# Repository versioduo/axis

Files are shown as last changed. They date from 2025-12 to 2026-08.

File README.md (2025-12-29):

# V2 axis
🧭 MIDI Orientation Sensor and Accelerometer

Sends MIDI Control Change messages with Quaternion or Euler orientation data.

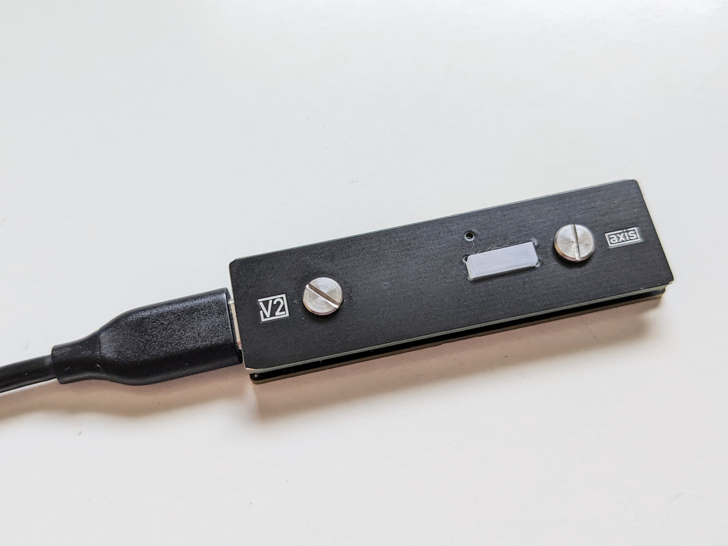
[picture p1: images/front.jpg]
axis hardware


## Setup
The device can be mounted at any orientation or angle, the reference frame / axes can be aligned to the current posion and stored in the device. This sequence identifies the Y axis (the axis of rotation between the button clicks) and the Z axis (the gravity at the second step):

- The device, or the body it is mounted on, points upwards / to the sky. A double-click of the the button, the LED turns green.

- The device points forward, the zero position. A single click, the LED turns orange. The axes of the sensor are now aligned and the rotation reset to zero.

- Any single click will set the rotation to zero, but not change the reference frame.

- A long-press double-click will store the calibration in the device, the LED flashes purple.

A long-press triple-click erases the stored data, the LED flashes purple.

## Control Change Mapping
Holding the device button down, suppresses all Control Change messages. The CC numbers can be configured in the Setting section. Pressing the blue button there, sends this single CC message; it can be used to map the CC in the Audio Workstation."

## Visualization
[versioduo.com/axis3d](https://versioduo.com/axis3d/)

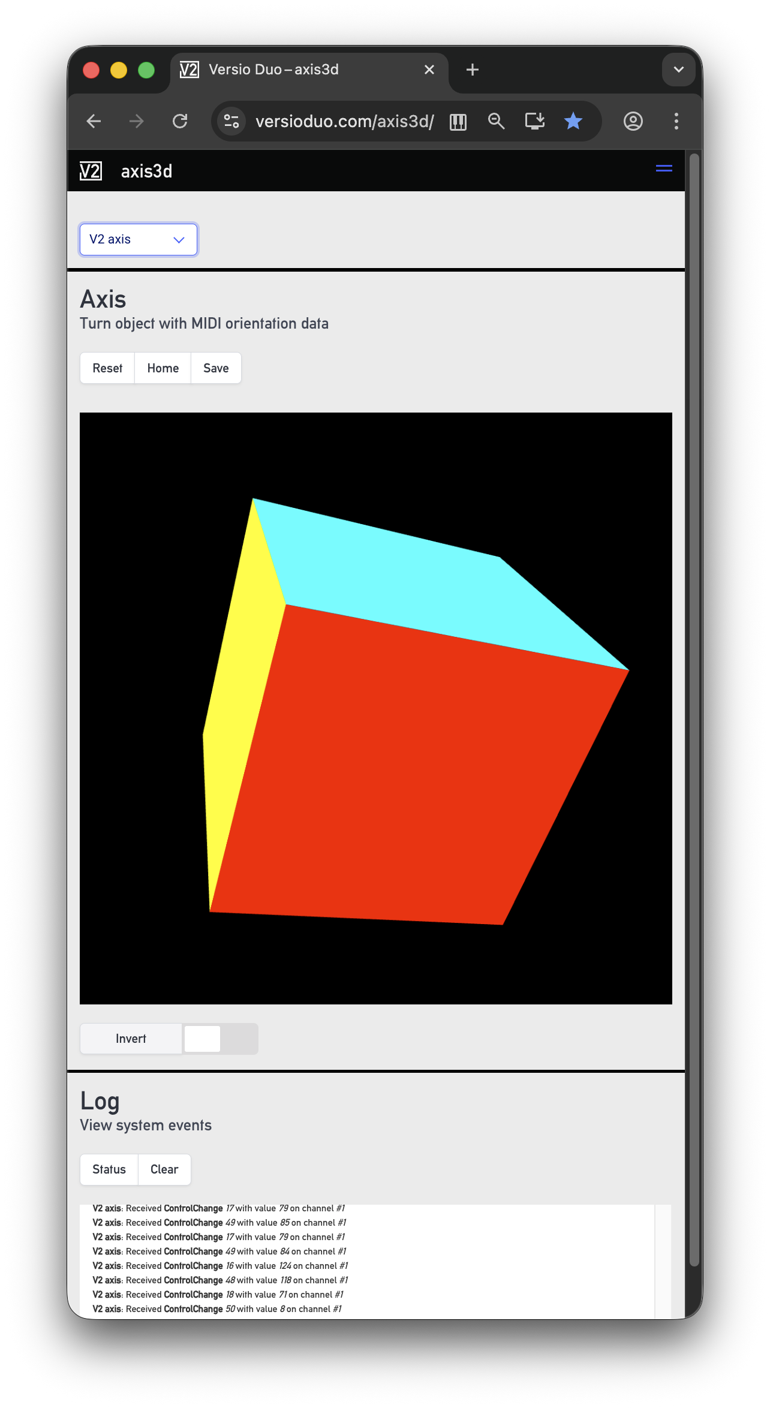
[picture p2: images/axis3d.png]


# Copying
Anyone can use this public domain work without having to seek authorisation, no one can ever own it.

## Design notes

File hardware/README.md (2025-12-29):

# V2 axis
🧭 MIDI Orientation Sensor and Accelerometer

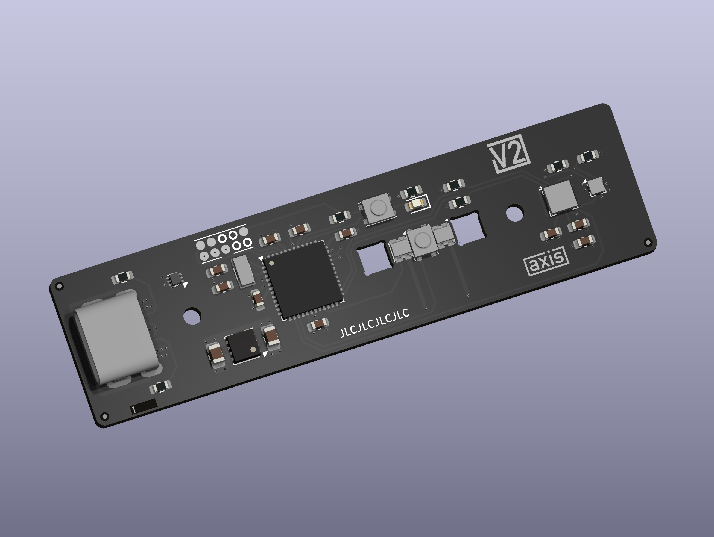
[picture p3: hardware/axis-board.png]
board


## Schematic
[PDF](axis.pdf)

## Bill Of Materials
[Interactive BOM](https://html-preview.github.io/?url=https://github.com/versioduo/axis/main/hardware/axis-bom.html)

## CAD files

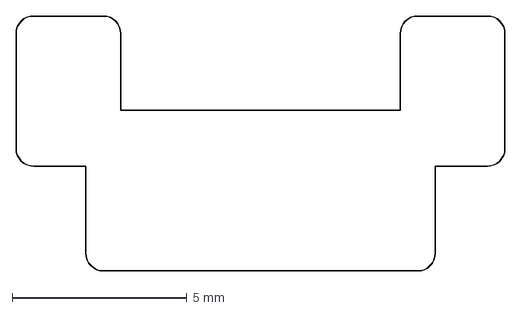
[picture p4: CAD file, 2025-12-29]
hardware/button-laser.dxf
14.0 x 7.30 mm

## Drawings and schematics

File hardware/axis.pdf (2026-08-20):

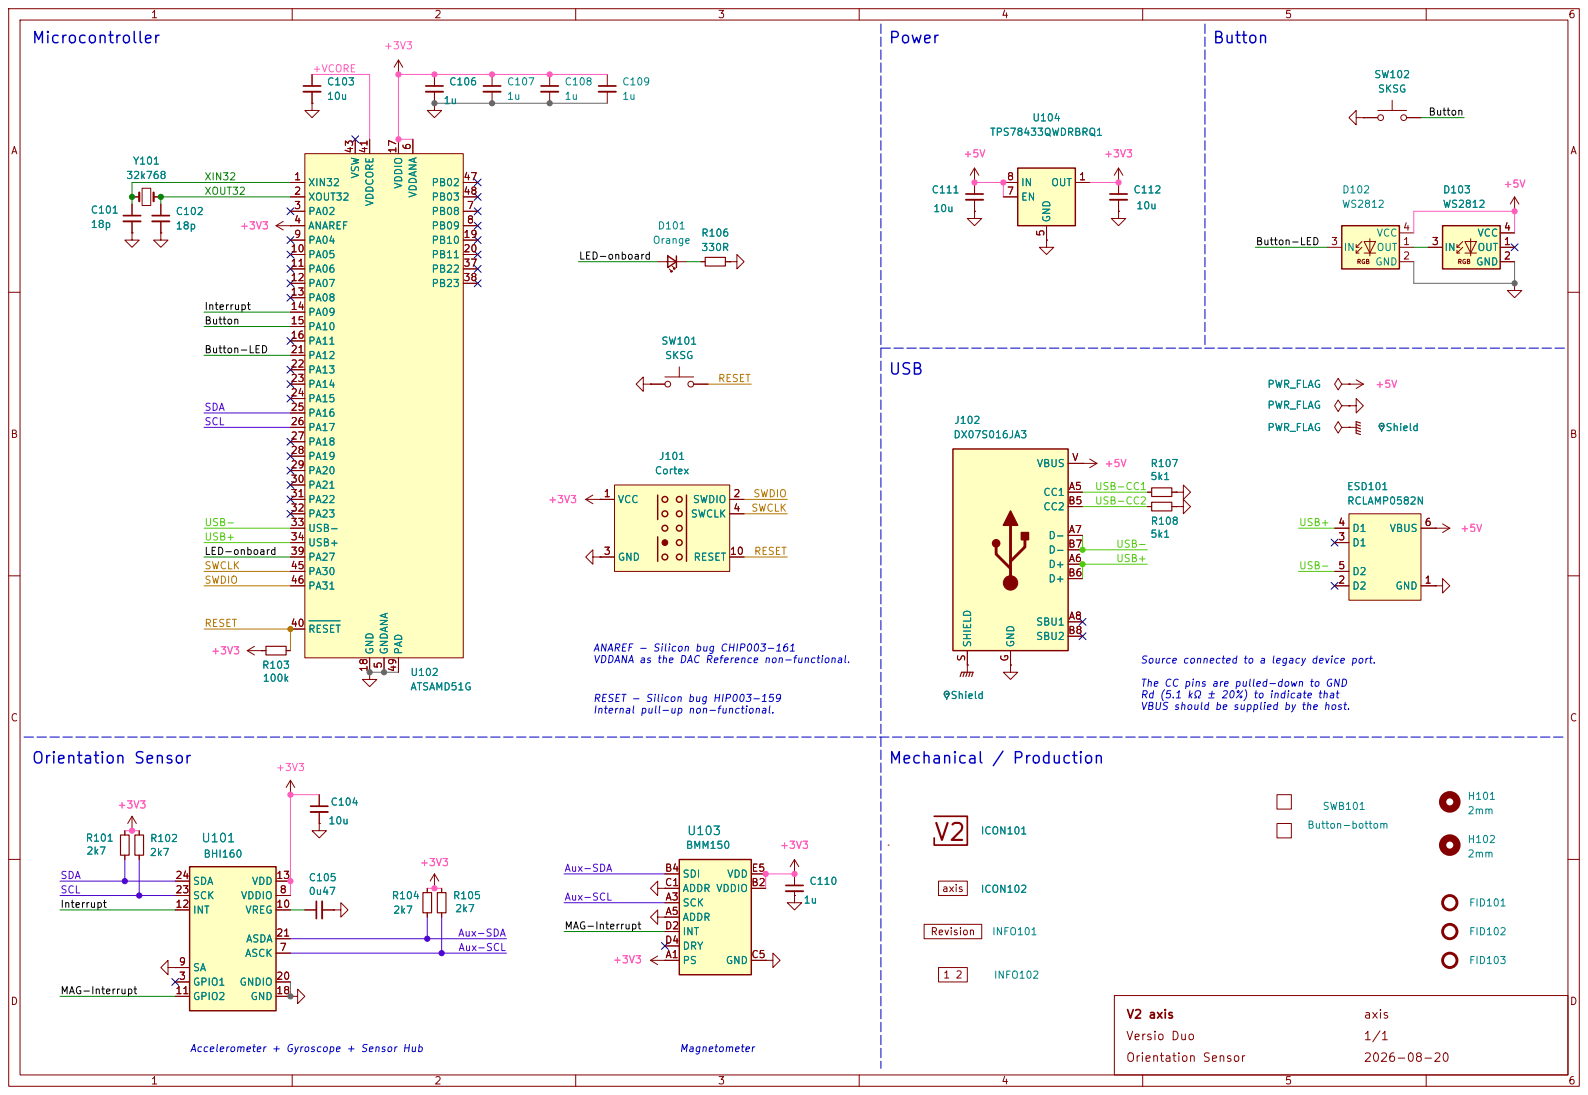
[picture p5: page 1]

Source connected to a legacy device port. The CC pins are pulled-down to GND

Rd (5.1 kΩ ± 20%) to indicate that VBUS should be supplied by the host. Magnetometer

Internal pull-up non-functional.

MAG-Interrupt SCL MAG-Interrupt

Accelerometer + Gyroscope + Sensor Hub

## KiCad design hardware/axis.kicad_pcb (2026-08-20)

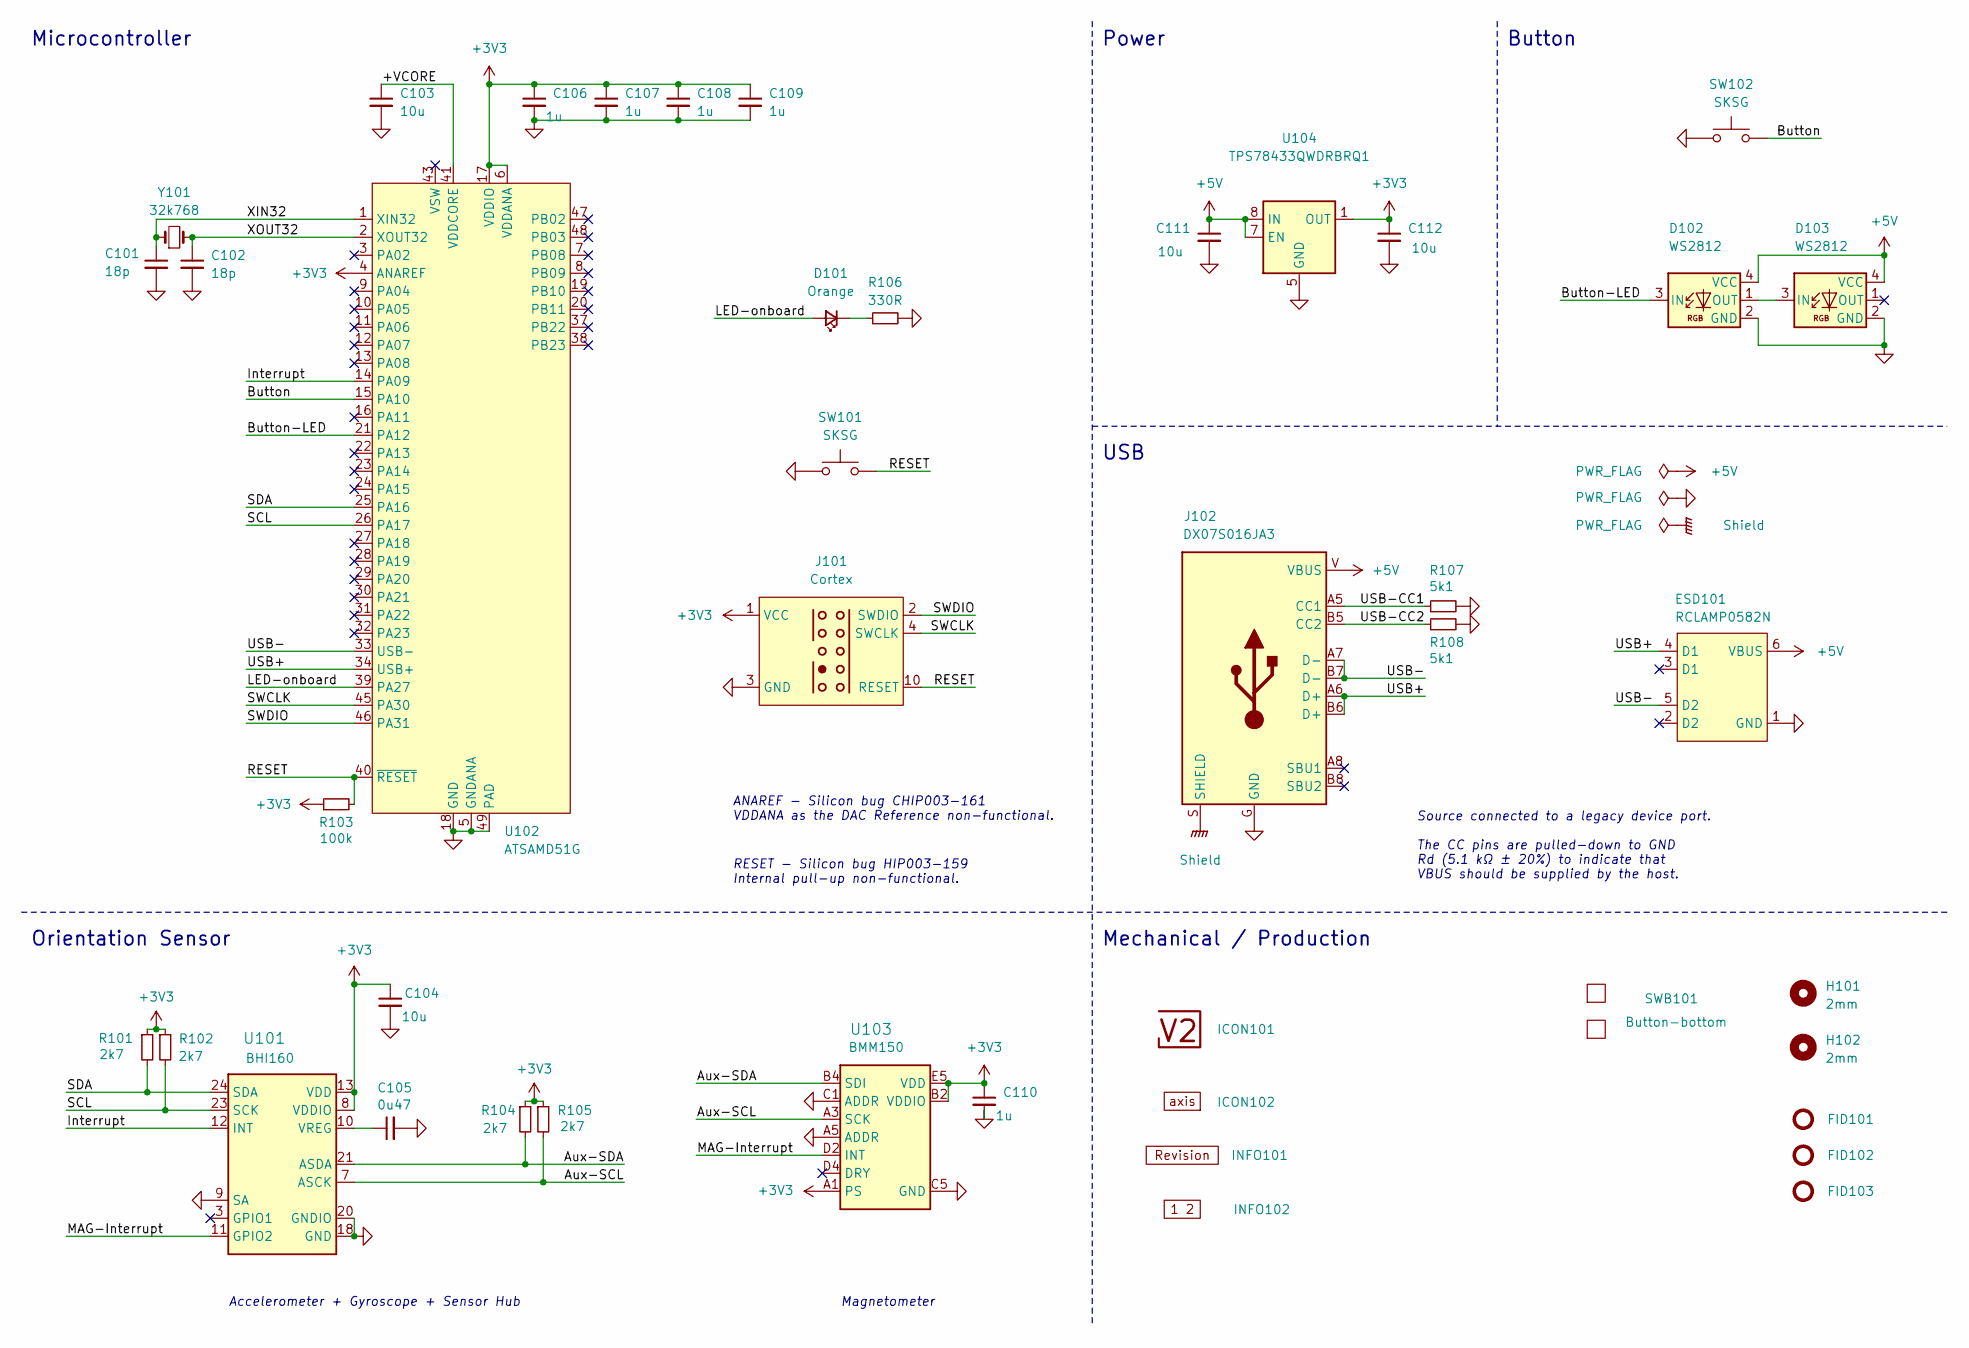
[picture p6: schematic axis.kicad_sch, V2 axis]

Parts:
C101, C102: 18p; C_1608; Rating 50V; Mouser 810-CGA3E2C0G1H180J
C103, C104: 10u; C_1608; Rating 10V; Mouser 810-C1608X6S1A106M
C105: 0u47; C_1608; Rating 50V; Mouser 810-CGA3E3X7R1H474KB
C106, C107, C108, C109, C110: 1u; C_1608; Rating 50V; Mouser 810-CGA3E3X7R1H105K0
C111, C112: 10u; C_2012; Rating 25V; Mouser 810-C2012X5R1E106K
D101: Orange; LED_1608; Rating 605nm; Mouser 755-SML-D12D1WT86
D102, D103: WS2812; WS2812-2020; Rating 15mA; LCSC C965555
ESD101: RCLAMP0582N; SLP1210N6; Rating 20kV; Mouser 947-RCLAMP0582N.TCT
FID101, FID102, FID103: Fiducial_Paste; Fiducial_0.5mm_Mask1mm_Paste
H101, H102: 2mm; MountingHole_2mm
ICON101: V2-logo; Logo_Small
ICON102: Board_axis; Board_axis_Small
INFO101: Revision
INFO102: Layer_Numbers-4
J101: Cortex
J102: DX07S016JA3; JAE_DX07S016JA3; Rating USB2.0; Mouser 656-DX07S016JA3R1500
R101, R102, R104, R105: 2k7; R_1608; Rating 100mW; Mouser 71-CRCW06032K70FKEAC
R103: 100k; R_1608; Rating 100mW; Mouser 71-CRCW0603100KFKEAC
R106: 330R; R_1608; Rating 100mW; Mouser 71-CRCW0603330RFKEAC
R107, R108: 5k1; R_1608; Rating 100mW; Mouser 71-CRCW06035K10FKEAC
SW101, SW102: SKSG; Rating 1.6N; Mouser 688-SKSGACE010
SWB101: Button-bottom; PCB_Button-bottom
U101: BHI160; LGA24-3x3; LCSC C464452
U102: ATSAMD51G; QFN-48-1EP_7x7mm_P0.5mm_EP5.45x5.45mm_ThermalVias; Rating Cortex-M4F; Mouser 556-ATSAMD51G19AMU
U103: BMM150; WLCSP-1.56x1.56; LCSC C171681
U104: TPS78433QWDRBRQ1; VSON-8-1_3x3mm_P0.65_EP1.65x2.4mm; Rating 300mA; Mouser 595-TPS78433QWDRBRQ1
Y101: 32k768; Crystal_SMD_3215-2Pin_3.2x1.5mm; Rating 10ppm; Mouser 815-ABS0716632.768KT

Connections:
+3V3: C104.1, C106.1, C107.1, C108.1, C109.1, C110.1, C112.1, J101.1 (VCC), R101.1, R102.1, R103.1, R104.1, R105.1, U101.8 (VDDIO), U101.13 (VDD), U102.4 (ANAREF), U102.6 (VDDANA), U102.17 (VDDIO), U102.36 (VDDIO), U102.44 (VDDIO), U103.A1 (PS), U103.B2 (VDDIO), U103.E5 (VDD), U104.1 (OUT)
+5V: C111.1, D102.4 (VCC), D103.4 (VCC), ESD101.6 (VBUS), J102.V (VBUS), U104.7 (EN), U104.8 (IN)
/+VCORE: C103.1, U102.41 (VDDCORE)
/Aux-SCL: R105.2, U101.7 (ASCK), U103.A3 (SCK)
/Aux-SDA: R104.2, U101.21 (ASDA), U103.B4 (SDI)
/Button: SW102.2, U102.15 (PA10)
/Button-LED: D102.3 (IN), U102.21 (PA12)
/Interrupt: U101.12 (INT), U102.14 (PA09)
/LED-onboard: D101.2 (A), U102.39 (PA27)
/MAG-Interrupt: U101.11 (GPIO2), U103.D2 (INT)
/RESET: J101.10 (RESET), R103.2, SW101.2, U102.40 (~RESET)
/SCL: R102.2, U101.23 (SCK), U102.26 (PA17)
/SDA: R101.2, U101.24 (SDA), U102.25 (PA16)
/SWCLK: J101.4 (SWCLK), U102.45 (PA30)
/SWDIO: J101.2 (SWDIO), U102.46 (PA31)
/Shield: J102.S (SHIELD)
/USB+: ESD101.4 (D1), J102.A6 (D+), J102.B6 (D+), U102.34 (USB+)
/USB-: ESD101.5 (D2), J102.A7 (D-), J102.B7 (D-), U102.33 (USB-)
/USB-CC1: J102.A5 (CC1), R107.1
/USB-CC2: J102.B5 (CC2), R108.1
/XIN32: C101.1, U102.1 (XIN32), Y101.1
/XOUT32: C102.1, U102.2 (XOUT32), Y101.2
GND: C101.2, C102.2, C103.2, C104.2, C105.2, C106.2, C107.2, C108.2, C109.2, C110.2, C111.2, C112.2, D102.2 (GND), D103.2 (GND), ESD101.1 (GND), J101.3 (GND), J101.5 (GND), J102.G (GND), R106.2, R107.2, R108.2, SW101.1, SW102.1, U101.9 (SA), U101.18 (GND), U101.20 (GNDIO), U102.5 (GNDANA), U102.18 (GND), U102.35 (GND), U102.42 (GND), U102.49 (PAD), U103.A5 (ADDR), U103.C1 (ADDR), U103.C5 (GND), U103.E1 (GND), U103.E3 (GND), U104.5 (GND), U104.9 (GND)
unnamed: D101.1 (K), R106.1
unnamed: D102.1 (OUT), D103.3 (IN)
unnamed: C105.1, U101.10 (VREG)

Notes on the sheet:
 ANAREF - Silicon bug CHIP003-161 VDDANA as the DAC Reference non-functional.
RESET -  Silicon bug HIP003-159 Internal pull-up non-functional.
 Source connected to a legacy device port. The CC pins are pulled-down to GND Rd (5.1 kΩ ± 20%) to indicate that VBUS should be supplied by the host.
Button
Mechanical / Production
Magnetometer
Power
Accelerometer + Gyroscope + Sensor Hub
Microcontroller
USB
Orientation Sensor

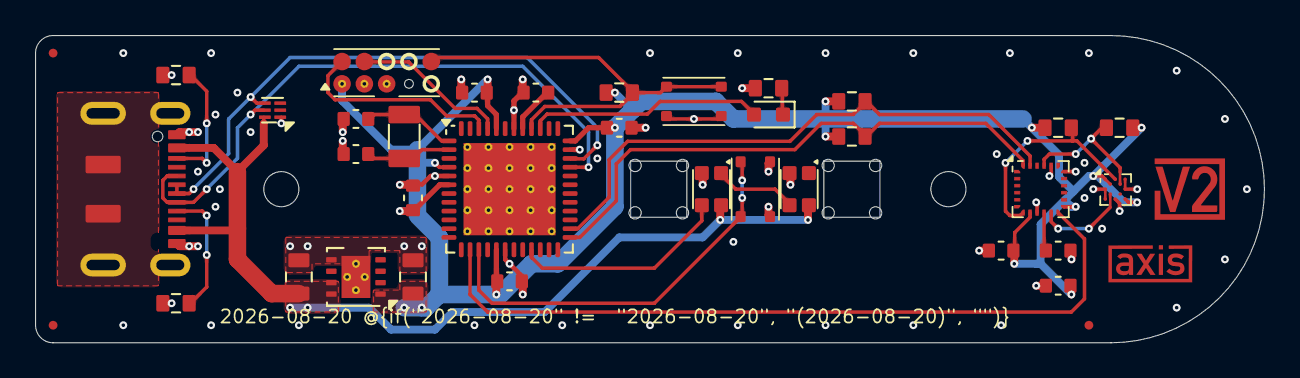
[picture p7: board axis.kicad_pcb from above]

Board: 4 copper layers, 70.0 x 17.5 mm, 43 parts (0 on the bottom side), 25 nets.

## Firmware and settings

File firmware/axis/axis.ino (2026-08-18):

#include <V2BHY1.h>
#include <V2Buttons.h>
#include <V2Device.h>
#include <V2LED.h>
#include <V2Link.h>
#include <V2MIDI.h>
#include <Wire.h>

namespace {
  V2Device::Info   Info{V2DeviceInfo("com.versioduo.axis", 8, "versioduo:samd:axis")};
  V2LED::WS2812<2> LED(PIN_LED_WS2812, sercom2, SPI_PAD_0_SCK_1, PIO_SERCOM);

  class Sensor : public V2BHY1 {
  public:
    Sensor() : V2BHY1(&Wire, PIN_SENSOR_INTERRUPT) {}

    // Subtract the recorded home postion to return the relative orientation to it.
    auto getRotation() -> V23D::Quaternion {
      return _setup.home * readCalibrated();
    }

    auto getAcceleration() -> V23D::Vector3 {
      return getGyroscope();
    }

    void updateLED() {
      switch (_setup.state) {
        case State::Init:
          LED.hsv({V2Colour::Cyan, 0.9, 0.2});
          break;

        case State::Up:
          LED.hsv({V2Colour ::Green, 0.9, 0.6});
          break;

        case State::Calibrated:
          LED.hsv({V2Colour::Orange, 0.9, 0.4});
          break;
      }
    }

    // The device points upwards. It is not required to point to the exact Z axis, an
    // angle smaller or larger than 90 degrees from the zero / Forward positon leads
    // to the same result. Only the rotation axis between the Tip and Forward matters.
    auto tip() {
      _setup = {
        .state = State::Up,
        .up    = getGravity().normalize(),
      };
      updateLED();
    }
    // The device points forward, the zero position. The rotation axis from Up
    // to Forward defines the Y (Pitch) axis of the device, the gravity defines
    // the Z (Yaw) axis. The button is pressed once again, the LED of the
    // now calibrated device turns orange.
    auto forward() -> bool {
      auto zAxis{getGravity().normalize()};

      // Require a defined / significant movement / angle to prevent wrong
      // calibration values.
      if (auto angle{V23D::radToDeg(_setup.up.angleBetween(zAxis))}; angle < 45.f || angle > 135.f) {
        _setup.state = State::Init;
        LED.flash({V2Colour::Red, 1, 0.6}, 0.3);
        updateLED();
        return false;
      }

      auto yAxis{_setup.up.cross(zAxis).normalize()};

      // Calculate the calibration / rotation quaternion to move the sensor's frame
      // into the device's frame.
      _setup.calibration = V23D::Attitude::accelerometerMagnetometer(zAxis, yAxis);
      _setup.state       = State::Calibrated;

      updateLED();
      return true;
    }

    // Record the current orientation. It will be substracted from future measurements
    // to use this as home / zero / start position.
    auto home() {
      if (_setup.state == State::Up)
        forward();

      _setup.home = readCalibrated().conjugate();
    }

    auto setup(bool compass, const V23D::Quaternion& calibration) {
      _compass = compass;

      _setup = {.calibration{calibration}};
      if (!calibration.equal(V23D::Quaternion()))
        _setup.state = State::Calibrated;

      home();
      updateLED();
    }

    auto calibration() const -> const V23D::Quaternion& {
      return _setup.calibration;
    }

  private:
    enum class State { Init, Up, Calibrated };
    bool _compass{};
    struct {
      State            state{};
      V23D::Vector3    up;
      V23D::Quaternion calibration;
      V23D::Quaternion home;
    } _setup;

    // Read the absolute orientation of the sensor using the magnetometer /
    // earth's magnetic north (it might jump when the magnetic field reading
    // is disturbed or not yet known).
    // Or read the orientation without using the magentometer (uses the rotation
    // after starting up, and the orientation might drift over time).
    auto read() -> V23D::Quaternion {
      return _compass ? getGeoOrientation() : getOrientation();
    }

    // Apply the calibration recorded by tip + forward sequence.
    auto readCalibrated() -> V23D::Quaternion {
      return _setup.calibration * read() * _setup.calibration.conjugate();
    }
  } Sensor;

  // Config, written to EEPROM.
  constexpr struct Configuration {
    uint8_t channel{};
    bool    compass{true};

    V23D::Quaternion calibration;

    struct {
      bool    enabled{};
      uint8_t yaw{V2MIDI::CC::GeneralPurpose1 + 4};
      uint8_t pitch{V2MIDI::CC::GeneralPurpose1 + 5};
      uint8_t roll{V2MIDI::CC::GeneralPurpose1 + 6};
    } euler;

    struct {
      bool    enabled{};
      uint8_t x{V2MIDI::CC::GeneralPurpose1 + 7};
      uint8_t y{V2MIDI::CC::GeneralPurpose1 + 8};
      uint8_t z{V2MIDI::CC::GeneralPurpose1 + 9};
    } gyroscope;
  } ConfigurationDefault;

  class Device : public V2Device {
  public:
    Device() : V2Device() {
      metadata.vendor      = "Versio Duo";
      metadata.product     = "V2 axis";
      metadata.description = "Orientation Sensor";
      metadata.home        = "https://versioduo.com/#axis";
      system.download      = "https://versioduo.com/download";
      system.configure     = "https://versioduo.com/configure";
      usb.ports.standard   = 0;
      configuration        = {.version{2}, .size{sizeof(config)}, .data{&config}};
      help.device          = "Accelerometer, Gyroscope, Magnetometer – MIDI Control Change messages with Quaternion or Euler data.";
      help.configuration   = "# Setup\n"
                             "The device can be mounted at any orientation or angle, the reference frame / axes can be aligned "
                             "to the current posion and stored in the device. This sequence identifies the Y axis (the axis of "
                             "rotation between the button clicks) and the Z axis (the gravity at the second step):\n"
                             "• The device, or the body it is mounted on, points upwards / to the sky. A double-click of the the "
                             "button, the LED turns green.\n"
                             "• The device points forward, the zero position. A single click, the LED turns orange. The axes of "
                             "the sensor are now aligned and the rotation reset to zero.\n"
                             "• Any single click will set the rotation to zero, but not change the reference frame.\n"
                             "• A long-press double-click will store the calibration in the device, the LED flashes purple.\n"
                             "A long-press triple-click erases the stored data, the LED flashes purple.\n"
                             "# Control Change Mapping\n"
                             "Holding the device button down, suppresses all Control Change messages. The CC numbers can be "
                             "configured in the Setting section. Pressing the blue button there, sends this single CC message; "
                             "it can be used to map the CC in the Audio Workstation.";
    }

    enum class CC {
      Quaternion        = V2MIDI::CC::GeneralPurpose1,
      Home              = V2MIDI::CC::Controller14,
      SaveConfiguration = V2MIDI::CC::Controller15,
      Light             = V2MIDI::CC::Controller89,
    };

    Configuration config{ConfigurationDefault};

    // Store the tip and home orientation in the EPROM.
    auto storeConfiguration() {
      config.calibration = Sensor.calibration();

      writeConfiguration();
      LED.flash({V2Colour::Magenta, 0.8, 0.5}, 0.3);
    }

    auto silent(bool on = true) {
      _silent = on;
    }

  private:
    bool _silent{};

    V2MIDI::CC::HighResolution<V2MIDI::CC::GeneralPurpose1, 4> _hires;
    uint32_t                                                   _usec{};
    struct {
      uint8_t w{};
      uint8_t x{};
      uint8_t y{};
      uint8_t z{};
    } _quaternion;

    struct {
      uint8_t yaw{};
      uint8_t roll{};
      uint8_t pitch{};
    } _euler;

    struct {
      uint8_t x{};
      uint8_t y{};
      uint8_t z{};
    } _gyroscope;

    V2MIDI::Packet _midi{};
    float          _lightMax{};

    auto handleReset() -> void override {
      _silent = false;
      _hires.reset();
      _lightMax   = 100.f / 127.f;
      _quaternion = {};
      _euler      = {};
      _gyroscope  = {};

      Wire.end();
      Wire.begin();
      Wire.setClock(800 * 1000);
      Wire.setTimeout(1);

      LED.reset();
      updateBrightness();
      Sensor.setup(config.compass, config.calibration);
    }

    auto updateBrightness() -> void {
      float min{0.05};
      float max{0.75};
      float range{(max - min) * _lightMax};
      LED.brightnessMax(min + range);
      Sensor.updateLED();
    }

    auto allNotesOff() {
      // Send the current values when 'Stop' is pressed in audio workstation.
      _hires.send(this, config.channel, uint8_t(CC::Quaternion) + 0);
      _hires.send(this, config.channel, uint8_t(CC::Quaternion) + 1);
      _hires.send(this, config.channel, uint8_t(CC::Quaternion) + 2);
      _hires.send(this, config.channel, uint8_t(CC::Quaternion) + 3);

      if (config.euler.enabled) {
        send(_midi.setControlChange(config.channel, config.euler.yaw, _euler.yaw));
        send(_midi.setControlChange(config.channel, config.euler.pitch, _euler.pitch));
        send(_midi.setControlChange(config.channel, config.euler.roll, _euler.roll));
      }

      if (config.gyroscope.enabled) {
        send(_midi.setControlChange(config.channel, config.gyroscope.x, _gyroscope.x));
        send(_midi.setControlChange(config.channel, config.gyroscope.y, _gyroscope.y));
        send(_midi.setControlChange(config.channel, config.gyroscope.z, _gyroscope.z));
      }
    }

    auto handleLoop() -> void override {
      if ((uint32_t)(V2Base::getUsec() - _usec) < 20 * 1000)
        return;

      if (_silent)
        return;

      {
        auto q{Sensor.getRotation()};
        if (_hires.set(uint8_t(CC::Quaternion) + 0, (q.w + 1.f) * 8191.f))
          _hires.send(this, config.channel, uint8_t(CC::Quaternion) + 0);

        if (_hires.set(uint8_t(CC::Quaternion) + 1, (q.x + 1.f) * 8191.f))
          _hires.send(this, config.channel, uint8_t(CC::Quaternion) + 1);

        if (_hires.set(uint8_t(CC::Quaternion) + 2, (q.y + 1.f) * 8191.f))
          _hires.send(this, config.channel, uint8_t(CC::Quaternion) + 2);

        if (_hires.set(uint8_t(CC::Quaternion) + 3, (q.z + 1.f) * 8191.f))
          _hires.send(this, config.channel, uint8_t(CC::Quaternion) + 3);

        if (config.euler.enabled) {
          auto e{V23D::Euler::quaternion({q.w, q.y, q.x, -q.z})};
          if (auto y{uint8_t((e.yaw / std::numbers::pi_v<float> + 1.f) / 2.f * 127.f)}; _euler.yaw != y) {
            send(_midi.setControlChange(config.channel, config.euler.yaw, y));
            _euler.yaw = y;
          }

          if (auto p{uint8_t((e.pitch / std::numbers::pi_v<float> + 1.f) / 2.f * 127.f)}; _euler.pitch != p) {
            send(_midi.setControlChange(config.channel, config.euler.pitch, p));
            _euler.pitch = p;
          }

          if (auto r{uint8_t((e.roll / std::numbers::pi_v<float> + 1.f) / 2.f * 127.f)}; _euler.roll != r) {
            send(_midi.setControlChange(config.channel, config.euler.roll, r));
            _euler.roll = r;
          }
        }
      }

      if (config.gyroscope.enabled) {
        auto center{[](float v) -> uint8_t { return ceilf((std::clamp((v + 1.f) / 2.f, 0.f, 1.f)) * 127.f); }};

        auto g{Sensor.getAcceleration()};
        if (auto x{center(g.x)}; _gyroscope.x != x) {
          send(_midi.setControlChange(config.channel, config.gyroscope.x, x));
          _gyroscope.x = x;
        }

        if (auto y{center(g.y)}; _gyroscope.y != y) {
          send(_midi.setControlChange(config.channel, config.gyroscope.y, y));
          _gyroscope.y = y;
        }

        if (auto z{center(g.z)}; _gyroscope.z != z) {
          send(_midi.setControlChange(config.channel, config.gyroscope.z, z));
          _gyroscope.z = z;
        }
      }

      _usec = V2Base::getUsec();
    }

    auto handleSend(V2MIDI::Packet* midi) -> bool override {
      usb.midi.send(*midi);
      return true;
    }

    auto handleControlChange(uint8_t channel, uint8_t controller, uint8_t value) -> void override {
      switch (controller) {
        case uint8_t(CC::Home):
          Sensor.home();
          break;

        case uint8_t(CC::SaveConfiguration):
          storeConfiguration();
          break;

        case uint8_t(CC::Light):
          _lightMax = float(value) / 127.f;
          updateBrightness();
          break;

        case V2MIDI::CC::AllSoundOff:
        case V2MIDI::CC::AllNotesOff:
          allNotesOff();
          break;
      }
    }

    auto handleSystemExclusive(const uint8_t* buffer, uint32_t len) -> void override {
      if (len < 20)
        return;

      // 0x7d == SysEx prototype/research/private ID
      if (buffer[1] != 0x7d)
        return;

      // Handle only JSON messages.
      if (buffer[2] != '{' || buffer[len - 2] != '}')
        return;

      // Read incoming message.
      JsonDocument json;
      if (deserializeJson(json, buffer + 2, len - 1))
        return;

      JsonObject test{json["test"]};
      if (!test)
        return;

      if (test["controller"].isNull())
        return;

      send(_midi.setControlChange(config.channel, test["controller"], 64));
    }

    auto handleSystemReset() -> void override {
      reset();
    }

    void exportLinks(JsonArray json) override {
      JsonObject jsonLink     = json.add<JsonObject>();
      jsonLink["description"] = "Rotating Cube";

      std::string link{"https://versioduo.com/sequencer?connect="};
      if (!usb.name.empty())
        link.append(usb.name);
      else
        link.append(metadata.product);
      jsonLink["target"] = link;
    }

    auto exportSystem(JsonObject json) -> void override {
      JsonObject jsonPower{json["sensor"].to<JsonObject>()};
      jsonPower["product"]  = Sensor.getProductID();
      jsonPower["revision"] = Sensor.getRevisionID();
      jsonPower["software"] = Sensor.getRAMVersion();
    }

    auto exportSettings(JsonArray json) -> void override {
      {
        JsonObject setting = json.add<JsonObject>();
        setting["type"]    = "title";
        setting["title"]   = "MIDI";
      }
      {
        JsonObject setting = json.add<JsonObject>();
        setting["type"]    = "number";
        setting["label"]   = "Channel";
        setting["min"]     = 1;
        setting["max"]     = 16;
        setting["input"]   = "select";
        setting["path"]    = "midi/channel";
      }

      {
        JsonObject setting = json.add<JsonObject>();
        setting["type"]    = "title";
        setting["title"]   = "Compass";
      }
      {
        JsonObject setting{json.add<JsonObject>()};
        setting["type"]  = "toggle";
        setting["label"] = "Enabled";
        setting["path"]  = "compass";
      }

      {
        JsonObject setting = json.add<JsonObject>();
        setting["type"]    = "title";
        setting["title"]   = "Euler";
      }
      {
        JsonObject setting{json.add<JsonObject>()};
        setting["type"]  = "toggle";
        setting["label"] = "Enabled";
        setting["path"]  = "euler/enabled";
      }
      {
        JsonObject setting{json.add<JsonObject>()};
        setting["type"]    = "controller";
        setting["label"]   = "Yaw";
        setting["test"]    = true;
        setting["path"]    = "euler/yaw";
        setting["default"] = ConfigurationDefault.euler.yaw;
      }
      {
        JsonObject setting{json.add<JsonObject>()};
        setting["type"]    = "controller";
        setting["label"]   = "Pitch";
        setting["test"]    = true;
        setting["path"]    = "euler/pitch";
        setting["default"] = ConfigurationDefault.euler.pitch;
      }
      {
        JsonObject setting{json.add<JsonObject>()};
        setting["type"]    = "controller";
        setting["label"]   = "Roll";
        setting["test"]    = true;
        setting["path"]    = "euler/roll";
        setting["default"] = ConfigurationDefault.euler.roll;
      }

      {
        JsonObject setting = json.add<JsonObject>();
        setting["type"]    = "title";
        setting["title"]   = "Gyroscope";
      }
      {
        JsonObject setting{json.add<JsonObject>()};
        setting["type"]  = "toggle";
        setting["label"] = "Enabled";
        setting["path"]  = "gyroscope/enabled";
      }
      {
        JsonObject setting{json.add<JsonObject>()};
        setting["type"]    = "controller";
        setting["label"]   = "X";
        setting["test"]    = true;
        setting["path"]    = "gyroscope/x";
        setting["default"] = ConfigurationDefault.gyroscope.x;
      }
      {
        JsonObject setting{json.add<JsonObject>()};
        setting["type"]    = "controller";
        setting["label"]   = "Y";
        setting["test"]    = true;
        setting["path"]    = "gyroscope/y";
        setting["default"] = ConfigurationDefault.gyroscope.y;
      }
      {
        JsonObject setting{json.add<JsonObject>()};
        setting["type"]    = "controller";
        setting["label"]   = "Z";
        setting["test"]    = true;
        setting["path"]    = "gyroscope/z";
        setting["default"] = ConfigurationDefault.gyroscope.z;
      }
    }

    auto importConfiguration(JsonObject json) -> void override {
      JsonObject jsonMidi{json["midi"]};
      if (jsonMidi) {
        if (!jsonMidi["channel"].isNull()) {
          uint8_t channel = jsonMidi["channel"];

          if (channel < 1)
            config.channel = 0;
          else if (channel > 16)
            config.channel = 15;
          else
            config.channel = channel - 1;
        }
      }

      if (!json["compass"].isNull())
        config.compass = json["compass"];

      JsonObject jsonCalibration{json["calibration"]};
      if (jsonCalibration) {
        config.calibration.w = jsonCalibration["w"];
        config.calibration.x = jsonCalibration["x"];
        config.calibration.y = jsonCalibration["y"];
        config.calibration.z = jsonCalibration["z"];
      }

      JsonObject jsonEuler{json["euler"]};
      if (jsonEuler) {
        if (!jsonEuler["enabled"].isNull())
          config.euler.enabled = jsonEuler["enabled"];

        config.euler.yaw   = jsonEuler["yaw"];
        config.euler.pitch = jsonEuler["pitch"];
        config.euler.roll  = jsonEuler["roll"];
      }

      JsonObject jsonGyroscope{json["gyroscope"]};
      if (jsonGyroscope) {
        if (!jsonGyroscope["enabled"].isNull())
          config.gyroscope.enabled = jsonGyroscope["enabled"];

        config.gyroscope.x = jsonGyroscope["x"];
        config.gyroscope.y = jsonGyroscope["y"];
        config.gyroscope.z = jsonGyroscope["z"];
      }

      reset();
    }

    auto exportConfiguration(JsonObject json) -> void override {
      {
        json["#midi"] = "The MIDI settings";
        auto m{json["midi"].to<JsonObject>()};
        m["#channel"] = "The channel to send notes and control values to";
        m["channel"]  = config.channel + 1;
      }

      json["#compass"] = "Use the compass for absolute coordinates";
      json["compass"]  = config.compass;

      {
        auto c{json["calibration"].to<JsonObject>()};
        c["#"] = "The rotation of the sensor to the device's zero position";
        c["w"] = serialized(String(config.calibration.w, 4));
        c["x"] = serialized(String(config.calibration.x, 4));
        c["y"] = serialized(String(config.calibration.y, 4));
        c["z"] = serialized(String(config.calibration.z, 4));
      }
      {
        auto e{json["euler"].to<JsonObject>()};
        e["#"]       = "The controller numbers for the Euler coordinates";
        e["enabled"] = config.euler.enabled;
        e["yaw"]     = config.euler.yaw;
        e["pitch"]   = config.euler.pitch;
        e["roll"]    = config.euler.roll;
      }
      {
        auto g{json["gyroscope"].to<JsonObject>()};
        g["#"]       = "The controller numbers for the gyroscope";
        g["enabled"] = config.gyroscope.enabled;
        g["x"]       = config.gyroscope.x;
        g["y"]       = config.gyroscope.y;
        g["z"]       = config.gyroscope.z;
      }
    }
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
    void loop() {
      if (!Device.usb.midi.receive(_midi))
        return;

      if (_midi.port == 0)
        Device.dispatch(&Device.usb.midi, &_midi);
    }

  private:
    V2MIDI::Packet _midi;
  } MIDI;

  class Button : public V2Buttons::Button {
  public:
    Button() : V2Buttons::Button(&_config, PIN_BUTTON) {}

  private:
    const V2Buttons::Config _config{.clickUsec{200 * 1000}, .holdUsec{500 * 1000}};

    auto handleUp() -> void {
      Device.silent(false);
    }

    auto handleHold(uint8_t count) -> void override {
      switch (count) {
        case 0:
          Device.silent();
          break;

        case 1:
          Device.storeConfiguration();
          break;

        case 2:
          Device.config.calibration = {};
          Device.reset();
          Device.storeConfiguration();
          break;
      }
    }

    auto handleClick(uint8_t count) -> void override {
      switch (count) {
        case 0:
          Sensor.home();
          break;

        case 1:
          Sensor.tip();
          break;
      }
    }
  } Button;
}

auto setup() -> void {
  Serial.begin(9600);
  LED.begin();
  Sensor.begin();
  Button.begin();
  Device.begin();
  Device.reset();
}

auto loop() -> void {
  LED.loop();
  MIDI.loop();
  Sensor.loop();
  V2Buttons::loop();
  Device.loop();

  if (Device.idle())
    Device.sleep();
}

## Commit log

2026-01-14 Update parts
    [axis.kicad_pcb, axis.kicad_sch]
2026-02-01 Update library
    [axis.kicad_pcb, axis.kicad_sch]
2026-02-05 Update I2C
2026-02-10 Use date as revision
    [axis.kicad_pcb, axis.kicad_sch]
2026-02-13 Replace Order_Number
    [axis-cover.kicad_pcb, axis-cover.kicad_sch, axis.kicad_pcb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]
2026-02-25 Export stencil
    [axis.kicad_pcb, axis.kicad_sch]
2026-03-14 Update ESD suppressor
    [axis.kicad_pcb, axis.kicad_sch]
2026-03-21 KiCad 10
    [axis.kicad_pcb, axis.kicad_sch]
2026-04-24 Update DRC
    [axis.kicad_pcb, axis.kicad_sch]
2026-05-11 Good Bye Imperial
    [axis.kicad_sch]
2026-08-20 Rounded edge
    [axis.kicad_pcb, axis.kicad_sch, back.kicad_pcb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]
